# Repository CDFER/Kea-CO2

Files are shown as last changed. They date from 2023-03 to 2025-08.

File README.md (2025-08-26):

# Kea CO2 ✨




Kea CO2 is an ESP32-based device designed to visualize CO2 levels. It offers real-time graphing capabilities through a web interface, an external backup clock, fail-safe data storage, timezone support, and time synchronization via an unlocked Wi-Fi network server (STA + AP mode). The PCB also supports JTAG debugging through a breakout connector.

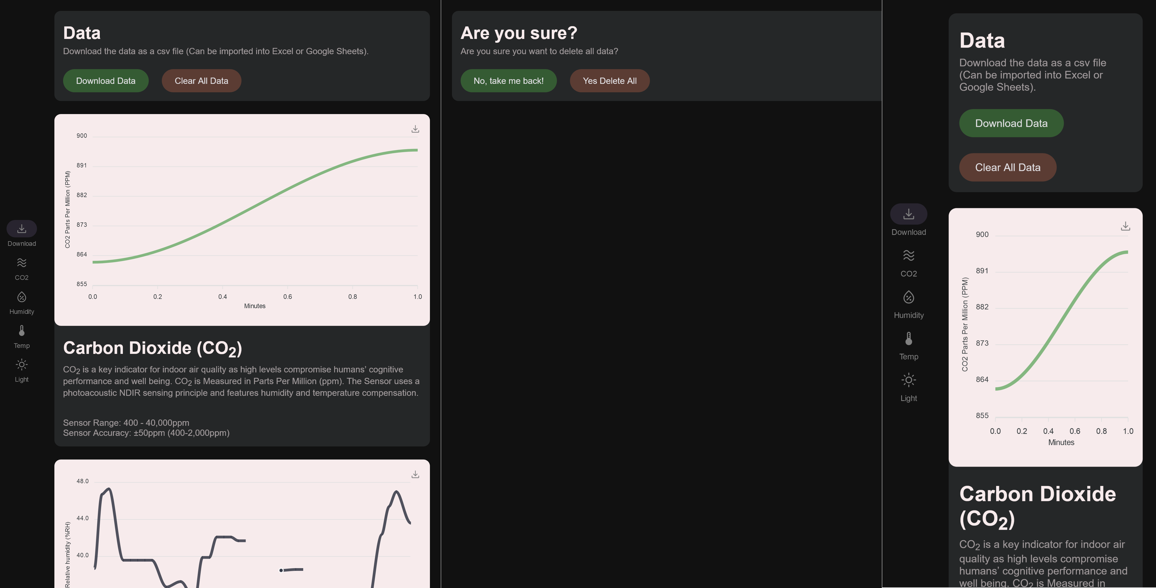
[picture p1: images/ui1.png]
User interface


## Known Limitations with Current Version

- Fixed 5-minute data recording interval.
- Fixed 2 MB maximum size data file (~300 days at 5-minute interval).

## Getting Started

If you encounter any issues while testing this code on a device, please consider adding them to this repository.

### Prerequisites

The following libraries are used in Kea CO2:

- espressif32 Arduino Framework
- AsyncTCP-esphome (LGPL (c) Hristo Gochkov @me-no-dev and others)
- ESPAsyncWebServer-esphome (LGPL (c) Hristo Gochkov @me-no-dev and others)
- NeoPixelBus (LGPL-3.0 license (c) Michael C. Miller and others)
- ArduinoJson (The MIT License (c) Benoit blanchon)
- Apex Charts (JavaScript) (The MIT License)

### Installation

1. Clone the repository.
2. Install the required libraries (PlatformIO does this automatically).
3. Compile and upload the code to the ESP32 device.

### Usage

The Kea CO2 device illuminates a strip of WS2812B addressable RGB LEDs to display the ambient CO2 level scale. The CO2 data is obtained from a Sensirion SCD4X sensor, and the LEDs are adjusted based on the ambient light conditions.

The device is capable of downloading a spreadsheet containing CO2, temperature, and humidity data. The data is stored in a fixed 2 MB file, which can hold up to 60 days of data at a fixed 1-minute recording interval.

To Sync the Time through Wifi just setup a hotspot with the name time and password 12345678
On Power the device will connect to the network and sync the time (Green Pulse if successful).

### Useful Extensions

- Better C++ Syntax
- Code Spell Checker
- Live Server
- PlatformIO IDE
- PuTTY for Standalone Serial Logger

### Wiring

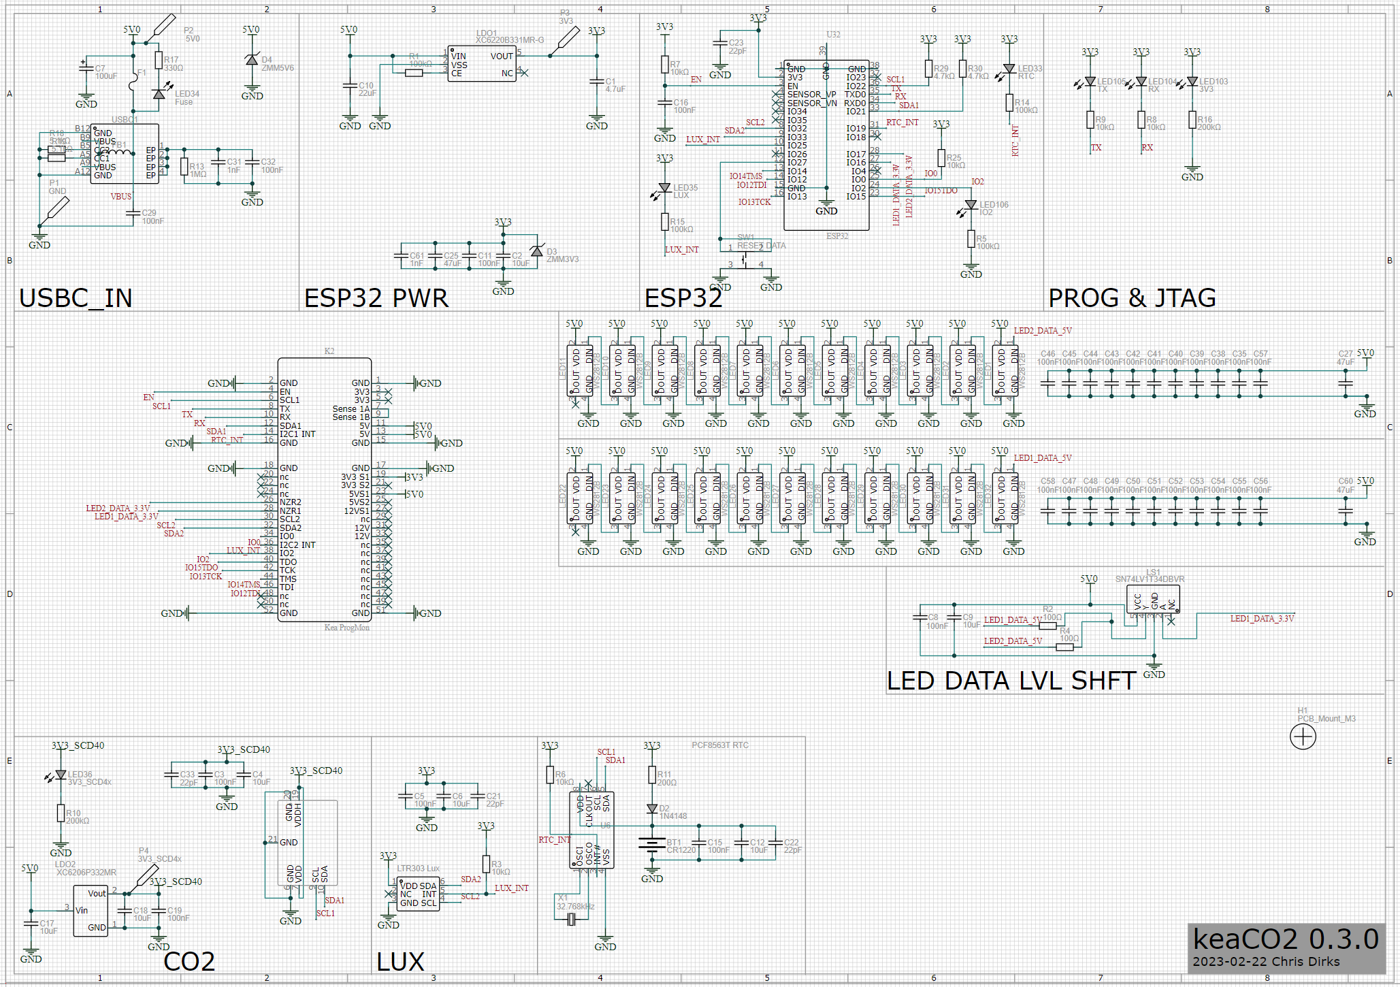
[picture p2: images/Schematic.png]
Schematic

| Name | Designator | Footprint | Quantity | Manufacturer Part |
|---|---|---|---|---|
| CR1220 | BT1 | CR1220 | 1 | BS-12-B2AA002 |
| 4.7uF | C1 | C0402 | 1 | CL05A475MP5NRNC |
| 10uF | C2-C18 | C0402 | 7 | CL05A106MQ5NUNC |
| 100nF | C3-58 | C0402 | 31 | CL05B104KO5NNNC |
| 100uF | C7 | L3.5-W2.8 | 1 | TAJB107K006RNJ |
| 22uF | C10 | C0603 | 1 | CL10A226MQ8NRNC |
| 22pF | C21-23,C33 | C0402 | 4 | 0402CG220J500NT |
| 47uF | C25,C27,C60 | C0805 | 3 | CL21A476MQYNNNE |
| 1nF | C31,C61 | C0402 | 2 | 0402B102K500NT |
| 1N148 | D2 | SOD-323 | 1 | 1N4148WS |
| ZMM3V3 | D3 | LL-34 | 1 | ZMM3V3-M |
| ZMM5V6 | D4 | LL-34D | 1 | ZMM5V6-M |
| Ferrite Bead 800ma | FB1 | FB0805 | 1 | GZ2012D101TF |
| XC6220B331MR-G | LDO1 | SOT-25-5  | 1 | XC6220B331MR-G |
| XC6206P332MR | LDO2 | SOT-23-3  | 1 | XC6206P332MR |
| WS2812B | LED1-32 | 3535RGB | 22 | XL-3535RGBC-WS2812  |
| RTC | LED33 | LED0603 | 1 | KT-0603R |
| 3V3_SCD4x | LED36 | LED0603 | 1 | 19-217/GHC-YR1S2/3T |
| 3V3 | LED103 | LED0603 | 1 | 19-217/GHC-YR1S2/3T |
| RX | LED104 | LED0603 | 1 | 19-213/Y2C-CQ2R2L |
| TX | LED105 | LED0603 | 1 | 19-213/Y2C-CQ2R2L |
| IO2 | LED106 | LED0603 | 1 | KT-0603R |
| SN74LV1T34DBVR | LS1 | SOT-23-5  | 1 | SN74LV1T34DBVR |
| 100kΩ | R1,R5,R14,R15 | R0402 | 4 | 0402WGF1003TCE |
| 100Ω | R2,R4 | R0402 | 2 | 0402WGF1000TCE |
| 10kΩ | R3,R6-R9,R25  | R0402 | 6 | 0402WGF1002TCE |
| 200kΩ | R10,R16 | R0402 | 2 | 0402WGF2003TCE |
| 200Ω | R11 | R0402 | 1 | 0402WGF2000TCE |
| 1MΩ | R13 | R0402 | 1 | 0402WGF1004TCE |
| 330Ω | R17 | R0402 | 1 | 0402WGF3300TCE |
| 5.1kΩ | R18,R19 | R0402 | 2 | 0402WGF5101TCE |
| 4.7kΩ | R29,R30 | R0402 | 2 | 0402WGF4701TCE |
| LTR303 Lux | U4 | SOT-363 | 1 | LTR-303ALS-01 |
| PCF8563T RTC | U6 | SOIC-8 | 1 | PCF8563T/5,518 |
| 918-418K2024S40004 | USBC1 | USB-C-SMD | 1 | 918-418K2024S40004  |
| 32.768kHz | X1 | FC-135R | 1 | Q13FC1350000400 |

## ✌️ Other

Some of the foundational work was done as part of a project with Terrestrial Assemblages with the support of Govett-Brewster Art Gallery / Len Lye Centre.

Thanks to everyone at @Espressif Systems for making a really awesome chip and porting it to Arduino.

Thanks to @LTRTNZ for putting up with my never-ending shit and @vincentd123 for helping me.

Made with love by Chris Dirks (@cd_fer) in Aotearoa New Zealand.

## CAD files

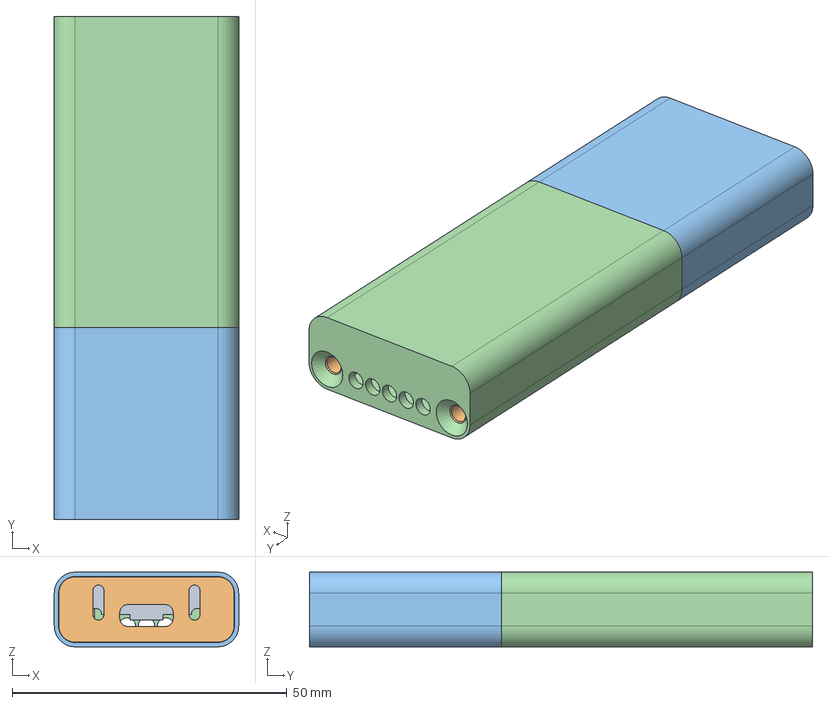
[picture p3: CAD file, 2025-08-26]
Case_Design.step
33.6 x 91.6 x 13.6 mm
Light Pipe Playground v9
Tube

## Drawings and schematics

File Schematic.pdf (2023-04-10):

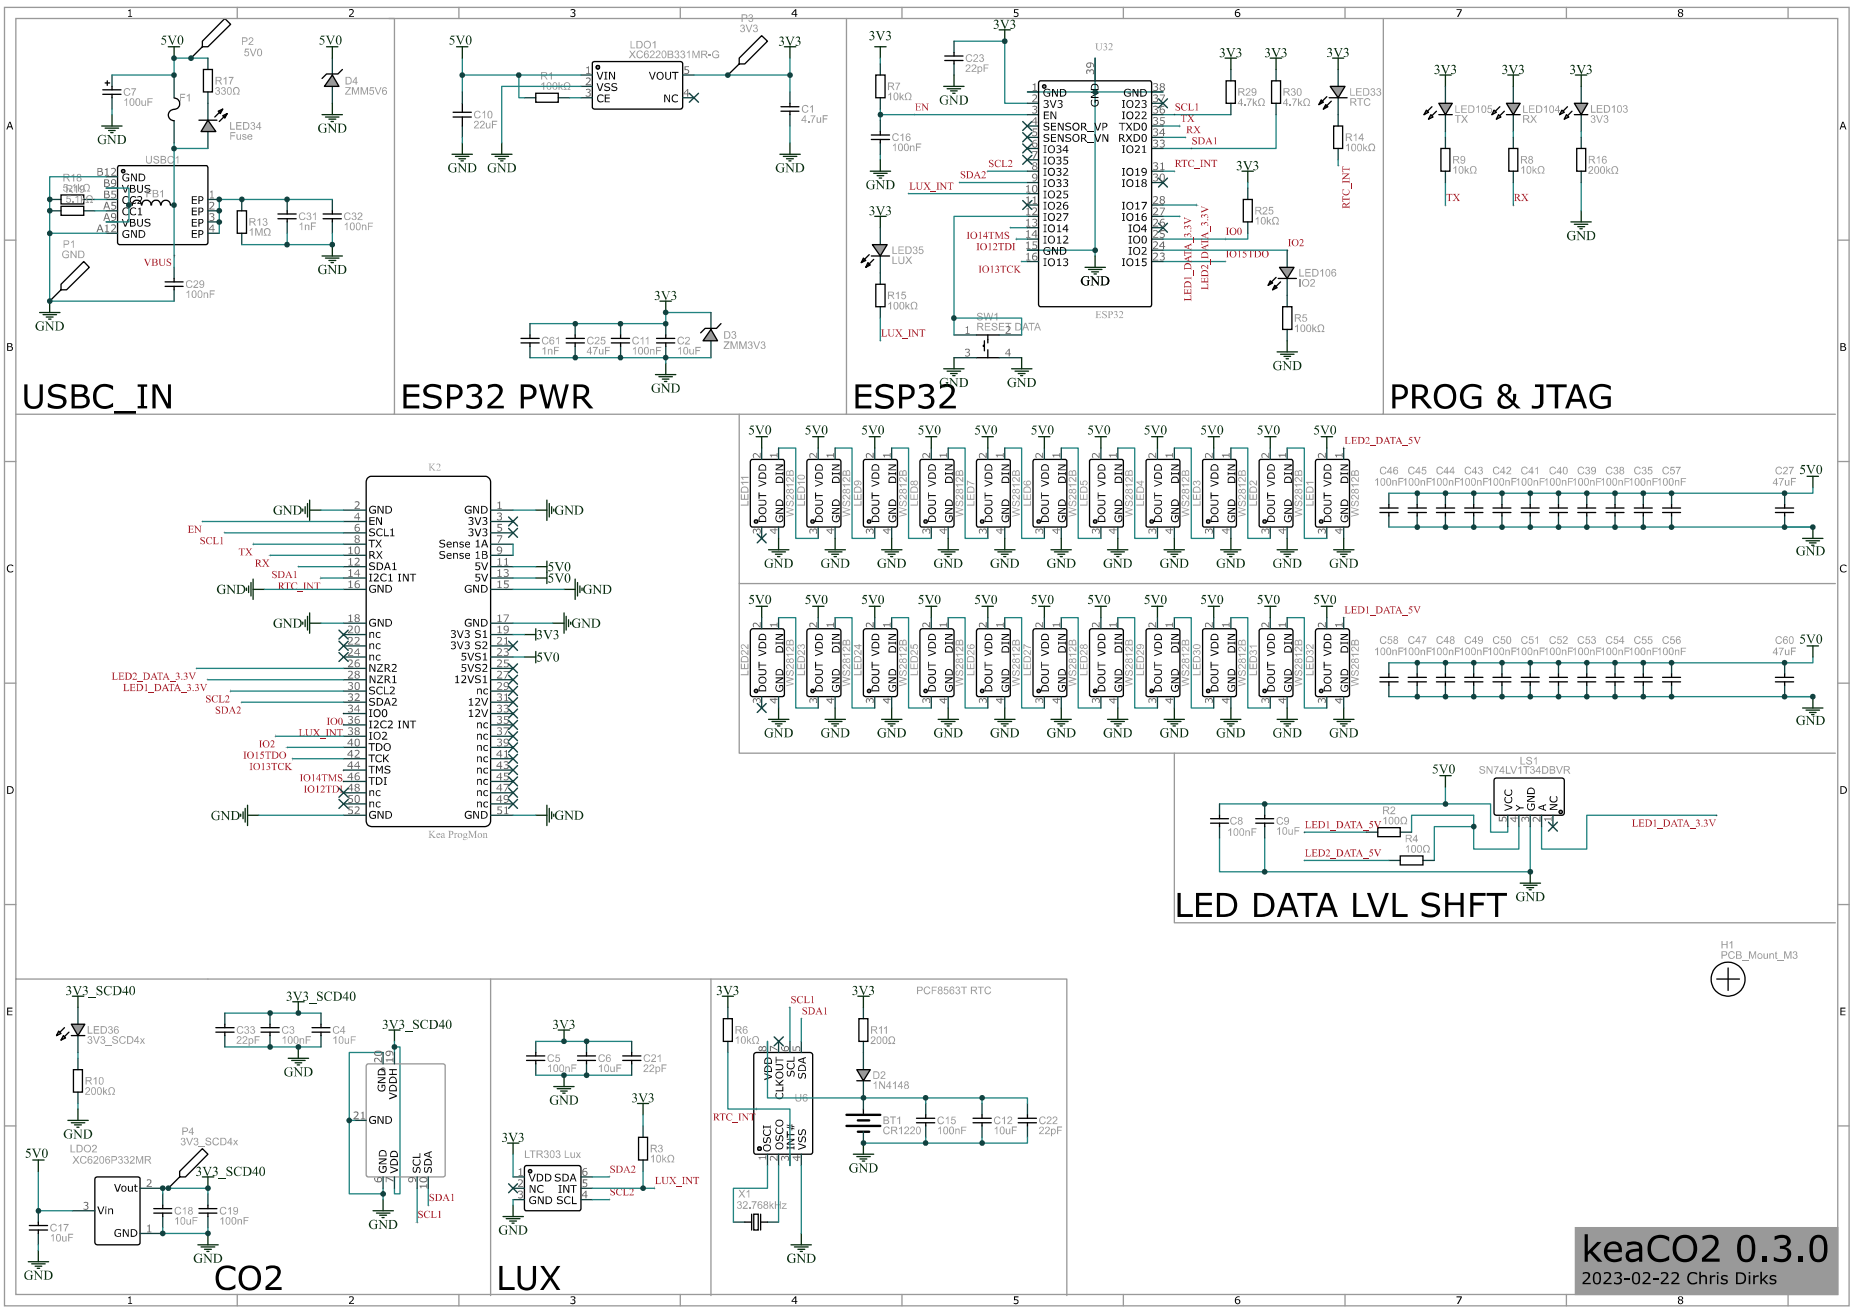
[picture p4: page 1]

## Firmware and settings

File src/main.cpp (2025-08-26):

/**
 * @file main.cpp
 * @brief Kea Studios CO2 Sensor Firmware
 * This firmware is designed to work with an ESP32 Wroom module and a Sensirion SCD40 or SCD41
 * sensor to measure ambient CO2 levels and display them on a strip of WS2812B addressable RGB
 * LEDs (Light Bar). The brightness of the LEDs is adjusted based on the ambient light level.
 * The firmware also includes a web server which displays graphs of CO2, humidity, and temperature,
 * and provides a CSV download for that data.
 * @author Chris Dirks (@CDFER)
 * @created 14/02/2023
 * @url https://www.keastudios.co.nz
 * @license HIPPOCRATIC LICENSE Version 3.0
 */

 //    __ __           ______          ___
 //   / //_/__ ___ _  / __/ /___ _____/ (_)__  ___
 //  / ,< / -_) _ `/ _\ \/ __/ // / _  / / _ \(_-<
 // /_/|_|\__/\_,_/ /___/\__/\_,_/\_,_/_/\___/___/
 //                  __      _        _  __             ____           __             __
 //   __ _  ___ ____/ /__   (_)__    / |/ /__ _    __  /_  / ___ ___ _/ /__ ____  ___/ /
 //  /  ' \/ _ `/ _  / -_) / / _ \  /    / -_) |/|/ /   / /_/ -_) _ `/ / _ `/ _ \/ _  /
 // /_/_/_/\_,_/\_,_/\__/ /_/_//_/ /_/|_/\__/|__,__/   /___/\__/\_,_/_/\_,_/_//_/\_,_/

#include <Arduino.h>

// -----------------------------------------
//
//    External Libraries
// 		for Wifi, Webserver and DNS
//
// -----------------------------------------
#include <ArduinoJson.h>
#include <DNSServer.h>
#include <WiFi.h>
#include <esp_wifi.h>

#include "AsyncJson.h"
#include "AsyncTCP.h"
#include "ESPAsyncWebServer.h"

// Onboard Flash Storage
#include <LittleFS.h>

// NTP and Timezone headers
#include "esp_sntp.h"
#include "time.h"

#ifdef OTA
#include <ArduinoOTA.h>
#include <ESPTelnet.h>
const char* ssid = "ssid";
const char* netpassword = "password";
ESPTelnet telnet;
#endif

// -----------------------------------------
//
//    Hardware Config
//
// -----------------------------------------
#include "NeoPixelBus.h"  // Light Bar
#include "ltr303.h"		  // LTR303 (Light sensor)
#include "pcf8563.h"	  // pcf8563 (Backup Clock)
#include "scd4x.h"		  // SCD4x (CO2 sensor)

// Define the data pin for the WS2812B LED light bar, the number of pixels,
// and an offset to adjust the temperature reading
#define PIXEL_COUNT 11	   // Number of Addressable Pixels to write data to (starts at pixel 1)
#define TEMP_OFFSET 10.6	   // The enclosure runs a bit hot, so reduce this to get a more accurate ambient temperature

// -----------------------------------------
//
//    LightBar Config
//
// -----------------------------------------

// Define the maximum and minimum CO2 values for the light bar,
// the frame time (in milliseconds) between light bar updates,
// the brightness factor (lux/BRIGHTNESS_FACTOR = LED brightness),
// and the maximum brightness setting for the LEDs
#define CO2_MAX 2000		 // Top of the CO2 light bar (when it transitions to warning flash)
#define CO2_MIN 400			 // Bottom of the light bar (baseline CO2 level)
#define FRAME_TIME 30		 // Milliseconds between frames (30ms = ~33.3fps maximum)
#define BRIGHTNESS_FACTOR 6	 // Lux/BRIGHTNESS_FACTOR = LED brightness
#define MAX_BRIGHTNESS 200	 // Maximum brightness setting for the WS2812B LEDs
enum lightBarModes {
	idleFrame,
	lightBarScale,
	flashRed,
	purplePulse,
	greenPulse,
	rgbTest,
	errorRed,
	off
};

// -----------------------------------------
//
//    Webserver Settings
//
// -----------------------------------------

// Define the time zone, SSID, and password for the WiFi network,
// as well as the record intervals for the CSV and JSON files
const char* time_zone = "NZST-12NZDT,M9.5.0,M4.1.0/3";	// Time zone (see https://github.com/nayarsystems/posix_tz_db/blob/master/zones.csv)
const char* password = "";								// Password of the WiFi access point (leave blank for no password)
#define CSV_RECORD_INTERVAL_SECONDS 60*5				// Record interval (in seconds) for the CSV file
#define JSON_RECORD_INTERVAL_SECONDS 5					// Record interval (in seconds) for the JSON file

// Define the filename, maximum size, and location for the CSV log file,
// as well as the IP and URL for the web server
char CSVLogFilename[] = "/Kea-CO2-Data.csv";			// Location of the CSV file
#define MAX_CSV_SIZE_BYTES 2000000						// Maximum size of the CSV file (2 MB)
#define CSV_LINE_MAX_CHARS 64							// Maximum size of the csvLine character buffer
const IPAddress localIP(4, 3, 2, 1);					// IP address of the web server (Samsung requires the IP to be in public space)
const IPAddress gatewayIP(4, 3, 2, 1);					// IP address of the network (should be the same as the local IP in most cases)
const String localIPURL = "http://4.3.2.1/index.html";	// URL to the web server (same as the local IP, but as a string with http and the landing page subdomain)

// -----------------------------------------
//
//    Helpful Defines (Don't Touch)
//
// -----------------------------------------

#define LIGHTBAR_MAX_POSITION PIXEL_COUNT * 255
#define LIGHTBAR_MIN_POSITION 255
#define LAST_PIXEL PIXEL_COUNT - 1				 // last Addressable Pixel to write data to (starts at pixel 0)
#define low8Bits(w) ((uint8_t)((w)))			 // returns bits 1 - 8 of a 32bit variable
#define high16Bits(w) ((uint16_t)((w) >> 16))	 // returns bits 17 - 32 of a 32bit variable

// -----------------------------------------
//
//    Global Variables
//
// -----------------------------------------

// Allocate the JSON document size in RAM https://arduinojson.org/v6/assistant to compute the size.
DynamicJsonDocument jsonDataDocument(23520);  // The size of the JSON document in bytes (about 23KB).
// This is used to store the data that will be sent to the web server.

#define JSON_DATA_POINTS_MAX 128  // The maximum number of data points to store in the JSON document.

TaskHandle_t lightBar = NULL;		  // A handle to the task that controls the light bar.
TaskHandle_t csvFileManager = NULL;	  // A handle to the task that writes sensor data to a CSV file.
TaskHandle_t sensorManager = NULL;	  // A handle to the task that reads sensor data.
TaskHandle_t webserver = NULL;		  // A handle to the task that runs the web server.
TaskHandle_t jsonFileManager = NULL;  // A handle to the task that writes JSON data to a file.

QueueHandle_t charsForCSVFileQueue;	 // A queue of character arrays which contain human readable sensor data.
// This is used to communicate between the sensor manager and the CSV file manager tasks.

QueueHandle_t jsonDataQueue;  // A queue of data points in doubles.
// This is used to communicate between the sensor manager and the JSON file manager tasks.

SemaphoreHandle_t jsonDocMutex;	 // A semaphore used to ensure that only one task accesses the JSON document at a time.
// This is used to prevent race conditions where two tasks try to access the document at the same time.

/**
 * @brief Rounds a double to a float with x decimal places
 * @param decimalPlaces The number of decimal places to round to
 * - 0: Returns the integer part of the value
 * - 1: Returns the value rounded to 1 decimal place
 * - 2: Returns the value rounded to 2 decimal places
 * - and so on...
 * @param value The input double to be rounded
 * @return A float rounded to the specified number of decimal places
 */
float roundToXDP(uint8_t decimalPlaces, double value) {	 // rounds a number to x decimal place
	return (float)(((int)(value * (10 * decimalPlaces) + 0.5)) / (10 * decimalPlaces));
}

/**
 * @brief Initializes the jsonDataDocument with default state, which includes graph colors but no data points.
 * This function clears the jsonDataDocument and creates three nested objects representing CO2, humidity, and temperature graphs.
 * Each object includes a "name", "color", and "y_title" field. Additionally, each object has a nested array called "data"
 * which initially has no elements.
 * @note This function assumes that the jsonDataDocument has already been initialized elsewhere in the program.
 * @see jsonDataDocument
 */
void initializeJson() {
	xSemaphoreTake(jsonDocMutex, portMAX_DELAY);  // ask for control of json doc

	jsonDataDocument.clear();

	JsonObject co2_graph_object = jsonDataDocument.createNestedObject();
	co2_graph_object["name"] = "CO2";
	co2_graph_object["color"] = "#70AE6E";
	co2_graph_object["y_title"] = "CO2 Parts Per Million (PPM)";
	JsonArray co2_graph_data_array = co2_graph_object["data"].createNestedArray();

	JsonObject humidity_graph_object = jsonDataDocument.createNestedObject();
	humidity_graph_object["name"] = "Humidity";
	humidity_graph_object["color"] = "#333745";
	humidity_graph_object["y_title"] = "Relative humidity (%RH)";
	JsonArray humidity_graph_data_array = humidity_graph_object["data"].createNestedArray();

	JsonObject temperature_graph_object = jsonDataDocument.createNestedObject();
	temperature_graph_object["name"] = "Temperature";
	temperature_graph_object["color"] = "#FE5F55";
	temperature_graph_object["y_title"] = "Temperature (Deg C)";
	JsonArray temperature_graph_data_array = temperature_graph_object["data"].createNestedArray();

	xSemaphoreGive(jsonDocMutex);  // release control of json doc
}

/**
 * @brief Convert CO2 level in parts per million to a position integer for a light bar display.
 * This function maps the input CO2 level to a position integer between 0 and LIGHTBAR_MAX_POSITION (each pixel has a position range of 0-255).
 * The mapping is linear and is based on the CO2_MIN, CO2_MAX, and LIGHTBAR_MAX_POSITION constants.
 * @param inputCO2 CO2 level in parts per million.
 * @return uint16_t The position integer for the light bar display.
 */
uint16_t mapCO2toPosition(double inputCO2) {
	if (inputCO2 > CO2_MIN) {
		return (uint16_t)((inputCO2 - CO2_MIN) * (LIGHTBAR_MAX_POSITION) / (CO2_MAX - CO2_MIN));
	} else {
		return (uint16_t)0;
	}
}

// Initializes the LED strip to black.
void initializeLightBar(NeoPixelBus<NeoGrbFeature, NeoEsp32I2s0Ws2812xMethod>& lightBar) {
	lightBar.Begin();
	lightBar.Show();
}

// Reads the light sensor and adjusts the brightness of the LED strip based on the light level.
bool updateBrightness(LTR303& lightSensor, uint8_t& brightness, uint8_t& targetBrightness) {
	double lux;
	if (lightSensor.getApproximateLux(lux)) {
		// Serial.printf("Lux: %.2f\n", lux);
		if (lux < (BRIGHTNESS_FACTOR * MAX_BRIGHTNESS)) {
			targetBrightness = (uint8_t)(lux / BRIGHTNESS_FACTOR);
		} else {
			targetBrightness = MAX_BRIGHTNESS;
		}
		if (brightness > targetBrightness) {
			brightness--;
			return true;
		} else if (brightness < targetBrightness) {
			brightness++;
			return true;
		}
	}
	return false;
}

// Updates the position of the lighting effect on the LED strip based on a target position.
void updatePosition(uint16_t& position, const uint16_t& targetPosition) {
	if (targetPosition < LIGHTBAR_MIN_POSITION) {
		position = LIGHTBAR_MIN_POSITION;
	} else if (targetPosition < LIGHTBAR_MAX_POSITION) {  // if position is in valid range
		if (position > targetPosition) {
			position--;
		} else if (position < targetPosition) {
			position += (targetPosition - position) / 32;
			position++;
		}
	}
}

// Updates the lighting effect on the LED strip.
void updateLightBar(NeoPixelBus<NeoGrbFeature, NeoEsp32I2s0Ws2812xMethod>& lightBar, const uint16_t& position, const uint8_t& brightness) {
	uint8_t redGreenMix = position / PIXEL_COUNT;	 // 0 - 255 version of position
	uint16_t mixingPixel = position / 255;			 // which pixel is the position at
	uint8_t mixingPixelBrightness = position % 255;	 // what is the local position of the pixel

	mixingPixel = LAST_PIXEL - mixingPixel;	 // reverse direction of lightbar (0th pixel is the top)

	RgbColor baseColor = RgbColor(redGreenMix, 255 - redGreenMix, 0).Dim(brightness);  // brew base color -> Green at bottom, Red at top

	lightBar.SetPixelColor(mixingPixel - 1, RgbColor(0));						// set one pixel above the mixing pixel to black
	lightBar.SetPixelColor(mixingPixel, baseColor.Dim(mixingPixelBrightness));	// set mixing pixel

	if (mixingPixel < LAST_PIXEL) {
		lightBar.ClearTo(baseColor, mixingPixel + 1, LAST_PIXEL);  // fill solid color to the bottom of the bar
	}

	lightBar.Show();
}

// Handles the target position notification and sets the local target position.
void handleTargetPositionNotification(uint16_t& targetPosition, uint32_t rawNotification, lightBarModes& lightBarMode) {
	uint16_t rawPosition = high16Bits(rawNotification);
	if (rawPosition != 0) {
		targetPosition = rawPosition;
	}

	lightBarModes rawMode = static_cast<lightBarModes>(low8Bits(rawNotification));

	if (rawMode != 0) {
		lightBarMode = rawMode;
	} else if (targetPosition > LIGHTBAR_MAX_POSITION) {
		lightBarMode = flashRed;
	}
	// Serial.printf("%i, %i, %i\n\r", lightBarMode, rawMode, rawPosition);
	return;
}

/**
 * @brief Controls addressable LED pixels and uses the I2C ambient light sensor.
 * This task controls an LED strip based on readings from an ambient light sensor, adjusting the brightness and position of a color gradient on the strip.
 * The gradient blends from green to red, and the position is set using xTaskNotify(). If the target position is above the maximum position, the strip flashes
 * red to indicate high CO2 levels. The code initializes the light strip and enters a loop that reads the light sensor, updates the position and brightness,
 * and shows the effect. There are also modes for testing and flashing a purple pulse.
 *
 * @param[in] parameter The task parameter (unused).
 */
void lightBarTask(void* parameter) {
	// Create the the lightbar object
	NeoPixelBus<NeoGrbFeature, NeoEsp32I2s0Ws2812xMethod> lightBar(PIXEL_COUNT + 1, PIXEL_DATA_PIN);  // uses i2s silicon remapped to any pin to drive led data

	//double lux;	 // The measured illumination level in lux.

	uint8_t targetBrightness = MAX_BRIGHTNESS;	// The target brightness value for the light bar, ranging from 0 to 255.
	uint8_t brightness = 255;					// The current brightness value for the light bar, ranging from 0 to 255.

	uint32_t rawNotification;							  // The raw position value for the light bar, filled from task notification
	uint16_t targetPosition = LIGHTBAR_MAX_POSITION / 3;  // The target position value for the light bar, ranging from 0 to LIGHTBAR_MAX_POSITION.
	uint16_t position = 0;								  // The current position value for the light bar, ranging from 0 to LIGHTBAR_MAX_POSITION.
	lightBarModes lightBarMode = lightBarScale;

	initializeLightBar(lightBar);

	LTR303 lightSensor;
	Wire1.begin(WIRE1_SDA_PIN, WIRE1_SCL_PIN, 500000);	// tested to be 380khz irl (400khz per data sheet)

#ifdef PRODUCTION_TEST
	if (!lightSensor.isConnected(Wire1, &Serial)) {
		lightBarMode = errorRed;
	} else {
		lightBarMode = rgbTest;
	}
#endif

	lightSensor.begin(GAIN_48X, EXPOSURE_100ms, true, Wire1);

	while (true) {
		if (updateBrightness(lightSensor, brightness, targetBrightness) == true) {
			if (lightBarMode == idleFrame) {
				lightBarMode = lightBarScale;
			}
		}
		//Serial.println(brightness);

		for (uint8_t i = 0; i < 4; i++) {	// get light reading every 4 frames
			if (xTaskNotifyWait(0, 0xFFFF, &rawNotification, 0) == pdTRUE) {
				handleTargetPositionNotification(targetPosition, rawNotification, lightBarMode);
			}

			switch (lightBarMode) {
			case idleFrame:
				if (position != targetPosition) {
					lightBarMode = lightBarScale;
				}
				vTaskDelay(pdMS_TO_TICKS(FRAME_TIME));  // time between frames
				break;

			case lightBarScale:
				updatePosition(position, targetPosition);
				updateLightBar(lightBar, position, brightness);
				if (position == targetPosition) {
					lightBarMode = idleFrame;
				}
				vTaskDelay(pdMS_TO_TICKS(FRAME_TIME));  // time between frames
				break;

			case flashRed:
				lightBar.ClearTo(RgbColor(0));
				lightBar.Show();
				vTaskDelay(500 / portTICK_PERIOD_MS);

				lightBar.ClearTo(RgbColor(255, 0, 0));
				lightBar.Show();
				vTaskDelay(500 / portTICK_PERIOD_MS);

				if (targetPosition < LIGHTBAR_MAX_POSITION) {
					lightBarMode = lightBarScale;
					position = LIGHTBAR_MAX_POSITION;
					brightness = MAX_BRIGHTNESS;
				}
				break;

			case purplePulse:
				for (size_t i = 0; i < MAX_BRIGHTNESS; i += 2) {
					lightBar.ClearTo(RgbColor(i, 0, i));
					lightBar.Show();
					vTaskDelay(pdMS_TO_TICKS(FRAME_TIME));  // time between frames
				}
				lightBar.ClearTo(RgbColor(0));
				lightBar.Show();
				lightBarMode = lightBarScale;
				break;

			case greenPulse:
				for (size_t i = 0; i < MAX_BRIGHTNESS; i += 2) {
					lightBar.ClearTo(RgbColor(0, i, 0));
					lightBar.Show();
					vTaskDelay(pdMS_TO_TICKS(FRAME_TIME));  // time between frames
				}
				lightBar.ClearTo(RgbColor(0));
				lightBar.Show();
				lightBarMode = lightBarScale;
				break;

			case rgbTest:  // Flash all pixels red, green, blue to test wiring and config is correct
				lightBar.ClearTo(RgbColor(255, 0, 0));
				lightBar.Show();
				vTaskDelay(1000 / portTICK_PERIOD_MS);
				lightBar.ClearTo(RgbColor(0, 255, 0));
				lightBar.Show();
				vTaskDelay(1000 / portTICK_PERIOD_MS);
				lightBar.ClearTo(RgbColor(0, 0, 255));
				lightBar.Show();
				vTaskDelay(1000 / portTICK_PERIOD_MS);
				lightBar.ClearTo(RgbColor(0, 0, 0));
				lightBar.Show();
				lightBarMode = lightBarScale;
				break;

			case errorRed:
				lightBar.ClearTo(RgbColor(MAX_BRIGHTNESS, 0, 0));
				lightBar.Show();
				vTaskSuspend(NULL);
				break;

			case off:
				lightBar.ClearTo(RgbColor(0));
				lightBar.Show();
				vTaskSuspend(NULL);
				break;

			default:
				break;
			}
		}
	}
}

// Callback function (get's called when time adjusts via NTP)
void onTimeAvailable(struct timeval* t) {
	ESP_LOGI("NTP", "Time available");
	vTaskResume(lightBar);
	xTaskNotify(lightBar, greenPulse, eSetValueWithOverwrite);
#ifndef OTA
	WiFi.disconnect();
#endif

	time_t epoch;
	struct tm gmt;
	time(&epoch);
	gmtime_r(&epoch, &gmt);
	Serial.println(&gmt, "\n\rGMT Time Set: %A, %B %d %Y %H:%M:%S\n\r");
}

void initializeNTPClient() {
	// Define the NTP servers to be used for time synchronization
	const char* ntpServer1 = "pool.ntp.org";
	const char* ntpServer2 = "time.nist.gov";
	const char* ntpServer3 = "time.google.com";

	sntp_set_time_sync_notification_cb(onTimeAvailable);

	configTzTime(time_zone, ntpServer1, ntpServer2, ntpServer3);
}

void setUpDNSServer(DNSServer& dnsServer, const IPAddress& localIP) {
	// Define the DNS interval in milliseconds between processing DNS requests
#define DNS_INTERVAL 10

	// Set the TTL for DNS response and start the DNS server
	dnsServer.setTTL(3600);
	dnsServer.start(53, "*", localIP);
}

void onClientConnected(WiFiEvent_t event) {
	uint32_t notification = static_cast<uint8_t>(purplePulse);
	xTaskNotify(lightBar, static_cast<uint8_t>(purplePulse), eSetValueWithOverwrite);
	return;
}

void startSoftAccessPoint(const char* password, const IPAddress& localIP, const IPAddress& gatewayIP) {
	// Define the maximum number of clients that can connect to the server
	const uint8_t MAX_CLIENTS = 4;

	// Define the WiFi channel to be used (channel 6 in this case)
	const uint8_t WIFI_CHANNEL = 6;

	// Set the WiFi mode to access point and station
	WiFi.mode(WIFI_MODE_APSTA);

	// Define the subnet mask for the WiFi network
	const IPAddress subnetMask(255, 255, 255, 0);

	// Configure the soft access point with a specific IP and subnet mask
	WiFi.softAPConfig(localIP, gatewayIP, subnetMask);

	// Generate a unique SSID based on the ESP32's MAC address
	char uniqueSSID[18] = { 0 };
	uint8_t mac[6];
	esp_read_mac(mac, ESP_MAC_WIFI_STA);
	snprintf(uniqueSSID, sizeof(uniqueSSID), "Kea-CO2-%02X", mac[5]);

	// Start the soft access point with the generated SSID, password, channel, and max number of clients
	WiFi.softAP(uniqueSSID, password, WIFI_CHANNEL, 0, MAX_CLIENTS);

	// Disable AMPDU RX on the ESP32 WiFi to fix a bug on Android
	// esp_wifi_stop();
	// esp_wifi_deinit();
	// wifi_init_config_t my_config = WIFI_INIT_CONFIG_DEFAULT();
	// my_config.ampdu_rx_enable = false;
	// esp_wifi_init(&my_config);
	// esp_wifi_start();
	// vTaskDelay(pdMS_TO_TICKS(100));  // Add a small delay

	// Register an event handler for when a station connects to the soft AP
	WiFi.onEvent(onClientConnected, WiFiEvent_t::ARDUINO_EVENT_WIFI_AP_STACONNECTED);
}
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
void loop() {
	vTaskSuspend(NULL);	 // Loop task Not Needed
}

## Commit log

2023-02-14 Huge Rewrite of Sensors and Leds
2023-02-19 Tidy and Streamline LED updates
2023-02-19 Fixed Ambient Light Adjustments
    [main.cpp]
2023-02-19 Updated Webserver For CO2 Data
    [Air_Quality_Data.csv, Kea-CO2-Data.csv, partitions_custom.csv]
2023-02-19 Added appendLineToCSV
    [Kea-CO2-Data.csv]
2023-02-27 Json Graphs
    [Kea-CO2-Data.csv, partitions_custom.csv]
2023-02-28 Fail Safe better type conversion
    [main.cpp]
2023-03-01 Clear Data Button added
2023-03-02 - added Core Dump - minified & gz web files - comments & bugfixes
    [partitions_custom.csv]
2023-03-02 - Update License - Add Proper Readme - Fix Spelling
    [main.cpp]
2023-03-13 Temp Fix, Auto Brightness Fix
    [main.cpp]
2023-03-16 Performance Improvements and Bugfixes
    [main.cpp]
2023-04-05 bugfix csv file manager
    [main.cpp]
2023-04-15 fixed SSID Duplication bugfixes added check for HTML on boot bugfix HTML
    [main.cpp]
2023-04-18 added lighbar state machine added onclient connect, pulse purple bugfix connect to open wifi tidy csv file functionality
    [main.cpp]
2023-04-22 increase upload speed, bugfix lightbar
    [main.cpp]
2023-08-06 Bugfixes, improve documentation, update depends
    [main.cpp]
2024-08-18 add support for ESP32S2 add support for OTA (alpha) add clang formatting
    [partitions_no_ota.csv, partitions_ota.csv]
